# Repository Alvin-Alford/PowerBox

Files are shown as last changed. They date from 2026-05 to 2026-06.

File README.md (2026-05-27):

#  PowerBox

> An all-in-one power solution for cyberdecks and portable embedded systems.

PowerBox is my custom-designed PCB that handles USB-C Power Delivery input, dual-cell lithium battery management, balance charging, and regulated power output, all in a single compact board. Designed to push up to **36W** of power to whatever you throw at it.

---

## Overview
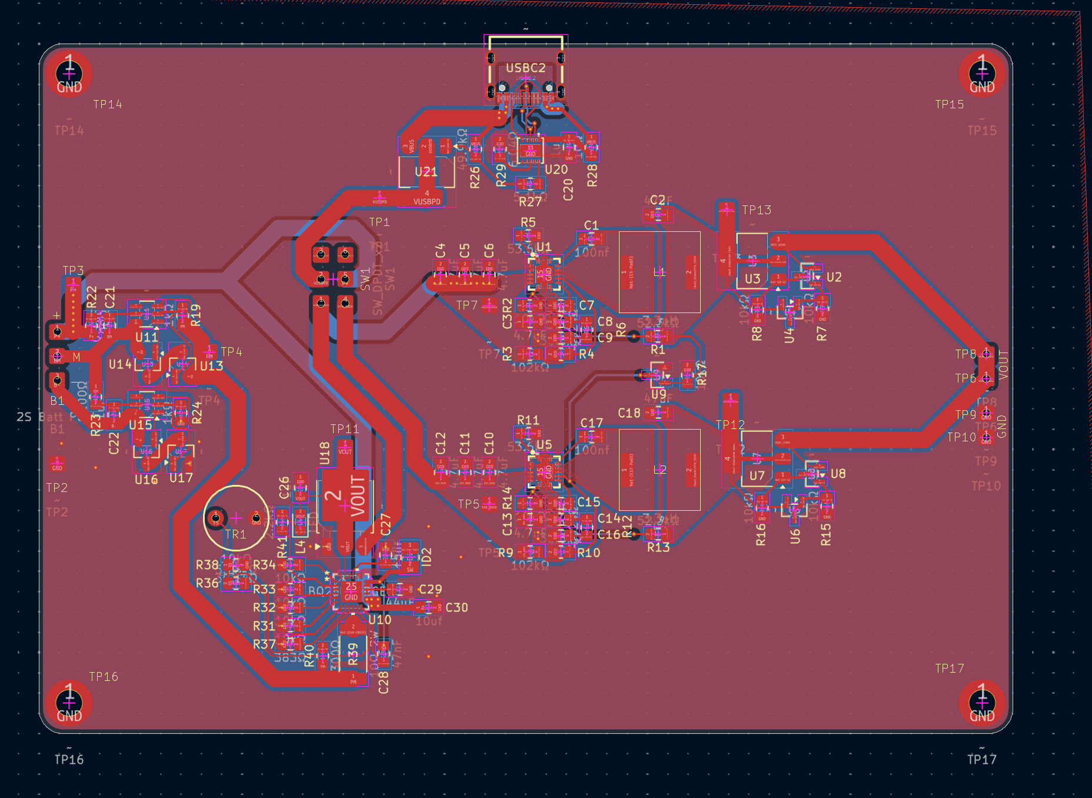
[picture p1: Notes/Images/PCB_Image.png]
PCB_IMAGE


*PowerBox was built to power DIY cyberdecks and portable computing projects that need more juice than a standard battery banks can provide.*

---

## Components

PowerBox is built around **7 core subsystems**:

### 1. USB-C Power Delivery Input
A USB-C port paired with a **PD sink controller** that negotiates **12V** from a PD-capable charger. At full load the circuit can draw up to **36W** which is well beyond what standard 5V USB can supply.

### 2. Dual Buck DC-DC Converters (×2)
Two **TPS54620** synchronous step-down converters provide regulated output voltages. The TPS54620 is a 6A, 17V capable device giving plenty of headroom for demanding loads.

### 3. Ideal Diode Circuits (×2)
When USB-C power is present, the battery-fed bucks are switched off to prevent backfeeding the charger. This creates a condition where the buck converter inputs can see negative voltages which is outside their rated range. The ideal diode circuits clamp this safely, acting as electronic diodes with near-zero forward voltage drop.

### 4. BMS Circuit (DW01A)
A battery management system built around the **DW01A** which is a popular and proven lithium-ion protection IC. Handles over-charge, over-discharge, and short-circuit protection for the cell pack.

### 5. 2S Balance Charger (BQ2588RGER)
A proper **2-series balance charger** using TI's **BQ2588RGER**, capable of up to **2A** charge current. Keeps both cells at equal state-of-charge for longevity and safety.

---

##  PCB

The PCB design files are in the [`PowerBox_PCB/`](./PowerBox_PCB) directory. Output gerbers and fabrication files are in [`Output/`](./Output).

---

## Design Logic

```
USB-C PD (12V, 36W)
        │
        ├──► Buck 1 (TPS54620) ──► Ideal Diode ──► Output Rail A
        │
        ├──► Buck 2 (TPS54620) ──► Ideal Diode ──► Output Rail B
        │
        └──► BQ2588RGER Balance Charger ──► 2S Li-Ion Pack
                                                  │
                                              DW01A BMS
                                                  │
                                            Battery Output
```

**Why did I choose 36W / USB-C PD?**

A 2S lithium pack needs to charge while simultaneously powering the system. At full system load, 15W standard USB-C isn't enough, it can't even charge an open MacBook. Requesting **12V via PD** and pulling up to **3A** gives the 36W headroom needed to charge the battery *and* run the load at the same time.

**Why two cells?**

More cells = more capacity. More capacity = the circuit can sustain high loads without the cells entering stress territory. A single-cell design at 36W draw would be asking for trouble (and possibly a fire).

---

## Repository Structure

```
PowerBox/
├── Notes/           # Design notes and calculations
├── Output/          # Gerber files and fabrication outputs
├── Parts/           # Bill of materials and component info
└── PowerBox_PCB/    # KiCad / PCB design files
```

---

## Key ICs

| Component | Part Number | Function |
|---|---|---|
| Buck Converter | TPS54620 | 6A, 17V synchronous step-down |
| Balance Charger | BQ2588RGER | 2S Li-Ion balance charger, 2A |
| BMS Controller | DW01A | Li-Ion protection IC |
| PD Sink | *(see Parts/)* | USB-C PD 12V negotiation |

---

## Zine

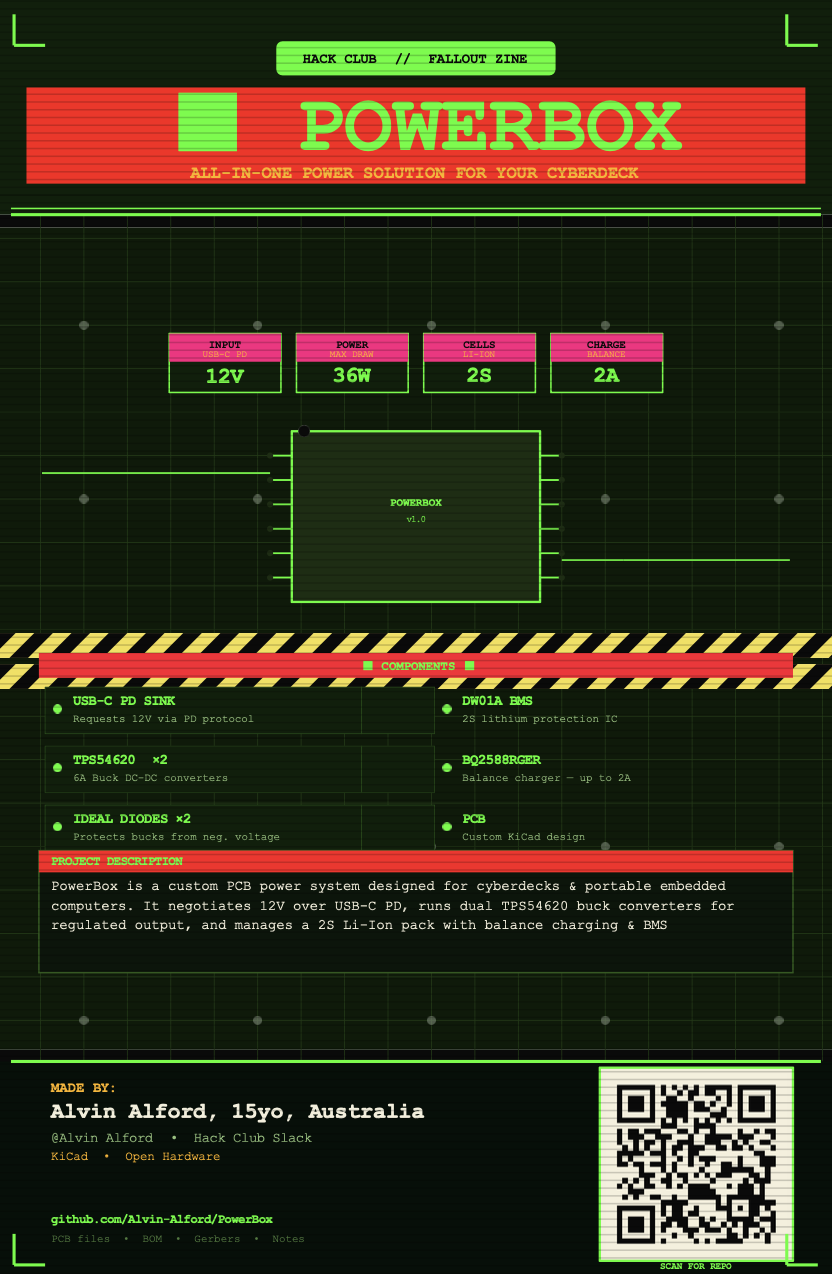
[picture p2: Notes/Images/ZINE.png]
ZINE


---

## License

See [LICENSE](./LICENSE) for details.

---

*Built by [Alvin-Alford](https://github.com/Alvin-Alford)*

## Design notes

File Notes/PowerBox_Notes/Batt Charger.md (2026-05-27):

1. Power Supply: https://www.lcsc.com/product-detail/C2847000.html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
2. https://www.lcsc.com/product-detail/C2761614.html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
3. https://www.lcsc.com/product-detail/C3013385.html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
4. https://www.lcsc.com/product-detail/C435392.html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
5.

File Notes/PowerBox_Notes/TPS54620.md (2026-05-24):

1. [TPS54620RHLR | TI | Price | In Stock | LCSC Electronics](https://www.lcsc.com/product-detail/C263274.html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)  
2. [NR1050M3R3N | Coilank | Price | In Stock | LCSC Electronics](https://www.lcsc.com/product-detail/C47327102.html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)  
3. [AT0805BRD074K02L | YAGEO | Price | In Stock | LCSC Electronics](https://www.lcsc.com/product-detail/C856950.html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)  
4. [FRC0805F1023TS | FOJAN | Price | In Stock | LCSC Electronics](https://www.lcsc.com/product-detail/C2999517.html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)  
5. [FRC0805F3652TS | FOJAN | Price | In Stock | LCSC Electronics](https://www.lcsc.com/product-detail/C2999585.html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)  
6. [ARG05BTC5232 | Viking | Price | In Stock | LCSC Electronics](https://www.lcsc.com/product-detail/C2758300.html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)  
7. [FRC0805F5362TS | FOJAN | Price | In Stock | LCSC Electronics](https://www.lcsc.com/product-detail/C5153984.html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)  
8. [FRC0805F1002TS | FOJAN | Price | In Stock | LCSC Electronics](https://www.lcsc.com/product-detail/C2907219.html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)  
9. [CL21A475KAQNNNE | Samsung Electro-Mechanics | Price | In Stock | LCSC Electronics](https://www.lcsc.com/product-detail/C1779.html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)  
10. [CL21C222JBFNNNE | Samsung Electro-Mechanics | Price | In Stock | LCSC Electronics](https://www.lcsc.com/product-detail/C28260.html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)  
11. [CL21A476MQYNNNE | Samsung Electro-Mechanics | Price | In Stock | LCSC Electronics](https://www.lcsc.com/product-detail/C16780.html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)  
12. [CC0805KRX7R9BB104 | YAGEO | Price | In Stock | LCSC Electronics](https://www.lcsc.com/product-detail/C49678.html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)  
13. [CC0805KRX7R9BB183 | YAGEO | Price | In Stock | LCSC Electronics](https://www.lcsc.com/product-detail/C113857.html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)  
14. [CC0805JRNPO9BN300 | YAGEO | Price | In Stock | LCSC Electronics](https://www.lcsc.com/product-detail/C107114.html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)  
15. [TPS54620 data sheet, product information and support | TI.com](https://www.ti.com/product/TPS54620)  
16. [TPS54620EVM-374 Evaluation board | TI.com](https://www.ti.com/tool/TPS54620EVM-374#tech-docs)  
17. [TPS54620 Step-Down Converter Evaluation Module User's Guide (Rev. B) - slvu281b.pdf](https://www.ti.com/lit/ug/slvu281b/slvu281b.pdf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)  
18. [Datasheet - LCSC Electronics](https://www.lcsc.com/datasheet/C263274.pdf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)  
19. [Power Designer](https://webench.ti.com/power-designer/switching-regulator/customize/1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)  
20. [Ceramic Capacitors | Electronic Components Distributor | LCSC Electronics](https://www.lcsc.com/category/1142.html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)

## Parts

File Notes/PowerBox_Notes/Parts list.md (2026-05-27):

1. [[TPS54620]]
2. [[Ideal Diode]]
3. [[Switch over controller]]
4. [[Batt Charger]]
5. [[BMS]]
6. [[USBPD]]

https://www.lcsc.com/product-detail/C84256.html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

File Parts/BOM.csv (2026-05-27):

Index | LCSC# | MPN | Manufacturer | Package | Customer # | Description | RoHS | Quantity | MOQ | Multiple | Unit Price($) | Extended Price($) | Product Link
1 | C84256 | NCD0805R1 | NATIONSTAR | 0805 |  | Red 630nm LED Indication - Discrete 1.6V~2.6V 0805 | yes | 50 | 50 | 50 | 0.0134 | 0.67 | https://www.lcsc.com/product-detail/C84256.html
2 | C2847000 | LM1084RS-5.0 | HTC | TO-252-3L |  | 5V Positive Fixed TO-252-3L Voltage Regulators - Linear, Low Drop Out (LDO) Regulators RoHS | yes | 3 | 1 | 1 | 0.5310 | 1.59 | https://www.lcsc.com/product-detail/C2847000.html
3 | C2761614 | BQ25887RGER | TI | QFN-24-EP(4x4) |  | Battery Balancing IC Lithium-ion/Polymer QFN-24-EP(4x4) | yes | 3 | 1 | 1 | 2.9554 | 8.87 | https://www.lcsc.com/product-detail/C2761614.html
4 | C3013385 | FRP2512J100 TS | FOJAN | 2512 |  | 2W 10Ω 200V Thick Film Resistor ±200ppm/℃ ±5% 2512 Chip Resistor - Surface Mount RoHS | yes | 20 | 20 | 20 | 0.0344 | 0.69 | https://www.lcsc.com/product-detail/C3013385.html
5 | C435392 | DFE252012F-1R0M=P2 | muRata | 1008 |  | 3.3A 1uH ±20% 4.7A 40mΩ 1008 Fixed Inductors RoHS | yes | 5 | 5 | 5 | 0.1374 | 0.69 | https://www.lcsc.com/product-detail/C435392.html
6 | C351410 | DW01A | PUOLOP | SOT-23-6L |  | Lithium Battery SOT-23-6L Battery Management RoHS | yes | 20 | 20 | 20 | 0.0428 | 0.86 | https://www.lcsc.com/product-detail/C351410.html
7 | C20917 | AO3400A | AOS | SOT-23 |  | N-Channel 30V Surface Mount SOT-23-3L | yes | 10 | 5 | 5 | 0.0828 | 0.83 | https://www.lcsc.com/product-detail/C20917.html
8 | C154901 | DMP6023LE-13 | DIODES | SOT-223 |  | P-Channel 60V 7A 2W Surface Mount SOT-223 | yes | 5 | 1 | 1 | 0.5912 | 2.96 | https://www.lcsc.com/product-detail/C154901.html
9 | C53444 | MMBT3906LT1G | onsemi | SOT-23 |  | Bipolar (BJT) Transistor PNP 40V 200mA 250MHz 225mW Surface Mount SOT-23 | yes | 50 | 50 | 50 | 0.0175 | 0.88 | https://www.lcsc.com/product-detail/C53444.html
10 | C263274 | TPS54620RHLR | TI | VQFN-14-EP(3.5x3.5) |  | 1.6MHz Step-down type Adjustable 800mV~15V 6A 4.5V~17V VQFN-14-EP(3.5x3.5) Voltage Regulators - DC DC Switching Regulators RoHS | yes | 4 | 1 | 1 | 0.9462 | 3.78 | https://www.lcsc.com/product-detail/C263274.html
11 | C47327102 | NR1050M3R3N | Coilank | SMD,10x10mm |  | 7.5A 3.3uH ±20% 14mΩ 10.7A SMD,10x10mm Fixed Inductors RoHS | yes | 5 | 5 | 5 | 0.1074 | 0.54 | https://www.lcsc.com/product-detail/C47327102.html
12 | C856950 | AT0805BRD074K02L | YAGEO | 0805 |  | 125mW 4.02kΩ Thin Film Resistor ±25ppm/℃ ±0.1% 0805 Chip Resistor - Surface Mount RoHS | yes | 10 | 5 | 5 | 0.0950 | 0.95 | https://www.lcsc.com/product-detail/C856950.html
13 | C2999517 | FRC0805F1023TS | FOJAN | 0805 |  | 102kΩ ±1% 125mW 0805 Thick Film Resistor | yes | 100 | 100 | 100 | 0.0018 | 0.18 | https://www.lcsc.com/product-detail/C2999517.html
14 | C2999585 | FRC0805F3652TS | FOJAN | 0805 |  | 36.5kΩ ±1% 125mW 0805 Thick Film Resistor | yes | 100 | 100 | 100 | 0.0013 | 0.13 | https://www.lcsc.com/product-detail/C2999585.html
15 | C2758300 | ARG05BTC5232 | Viking | 0805 |  | 52.3kΩ ±0.1% 125mW 0805 Thin Film Resistor | yes | 20 | 20 | 20 | 0.0341 | 0.68 | https://www.lcsc.com/product-detail/C2758300.html
16 | C5153984 | FRC0805F5362TS | FOJAN | 0805 |  | 53.6kΩ ±1% 125mW 0805 Thick Film Resistor | yes | 100 | 100 | 100 | 0.0019 | 0.19 | https://www.lcsc.com/product-detail/C5153984.html
17 | C2907219 | FRC0805F1002TS | FOJAN | 0805 |  | 10kΩ ±1% 125mW 0805 Thick Film Resistor | yes | 100 | 100 | 100 | 0.0021 | 0.21 | https://www.lcsc.com/product-detail/C2907219.html
18 | C1779 | CL21A475KAQNNNE | Samsung Electro-Mechanics | 0805 |  | 4.7uF ±10% 25V Ceramic Capacitor X5R 0805 | yes | 20 | 20 | 20 | 0.0184 | 0.37 | https://www.lcsc.com/product-detail/C1779.html
19 | C28260 | CL21C222JBFNNNE | Samsung Electro-Mechanics | 0805 |  | 2.2nF ±5% 50V Ceramic Capacitor C0G 0805 | yes | 10 | 10 | 10 | 0.0295 | 0.30 | https://www.lcsc.com/product-detail/C28260.html
20 | C16780 | CL21A476MQYNNNE | Samsung Electro-Mechanics | 0805 |  | 47uF ±20% 6.3V Ceramic Capacitor X5R 0805 | yes | 10 | 10 | 10 | 0.0556 | 0.56 | https://www.lcsc.com/product-detail/C16780.html
21 | C49678 | CC0805KRX7R9BB104 | YAGEO | 0805 |  | 100nF ±10% 50V Ceramic Capacitor X7R 0805 | yes | 100 | 100 | 100 | 0.0058 | 0.58 | https://www.lcsc.com/product-detail/C49678.html
22 | C113857 | CC0805KRX7R9BB183 | YAGEO | 0805 |  | 18nF ±10% 50V Ceramic Capacitor X7R 0805 | yes | 100 | 100 | 100 | 0.0082 | 0.82 | https://www.lcsc.com/product-detail/C113857.html
23 | C107114 | CC0805JRNPO9BN300 | YAGEO | 0805 |  | 30pF ±5% 50V Ceramic Capacitor NP0 0805 | yes | 100 | 100 | 100 | 0.0076 | 0.76 | https://www.lcsc.com/product-detail/C107114.html
24 | C7471904 | HUSB238_002DD | Hynetek | DFN-10L(3x3) |  | DFN-10L(3x3) Interface Controllers RoHS | yes | 3 | 1 | 1 | 0.5107 | 1.53 | https://www.lcsc.com/product-detail/C7471904.html
25 | C165948 | TYPE-C-31-M-12 | Korean Hroparts Elec | SMD |  | USB-C (USB TYPE-C) Receptacle Connector 16 Position Surface Mount | yes | 5 | 5 | 5 | 0.1719 | 0.86 | https://www.lcsc.com/product-detail/C165948.html
26 | C440198 | GRM21BR61H106KE43L | muRata | 0805 |  | 10uF ±10% 50V Ceramic Capacitor X5R 0805 | yes | 20 | 10 | 10 | 0.0795 | 1.59 | https://www.lcsc.com/product-detail/C440198.html
27 | C107154 | CC0805KRX7R9BB473 | YAGEO | 0805 |  | 47nF ±10% 50V Ceramic Capacitor X7R 0805 | yes | 200 | 100 | 100 | 0.0074 | 1.48 | https://www.lcsc.com/product-detail/C107154.html
28 | C5439718 | MF52B103F3435L100 | SURGING | - |  | NTC Thermistor 10kΩ | yes | 5 | 5 | 5 | 0.1121 | 0.56 | https://www.lcsc.com/product-detail/C5439718.html
29 | C2907232 | FRC0805F1001TS | FOJAN | 0805 |  | 1kΩ ±1% 125mW 0805 Thick Film Resistor | yes | 100 | 100 | 100 | 0.0020 | 0.20 | https://www.lcsc.com/product-detail/C2907232.html
30 | C17415 | 0805W8F100JT5E | UNI-ROYAL | 0805 |  | 10Ω ±1% 125mW 0805 Thick Film Resistor | yes | 100 | 100 | 100 | 0.0029 | 0.29 | https://www.lcsc.com/product-detail/C17415.html
31 | C105577 | RC0805FR-07100RL | YAGEO | 0805 |  | 125mW 100Ω 150V Thick Film Resistor ±100ppm/℃ ±1% 0805 Chip Resistor - Surface Mount RoHS | yes | 100 | 100 | 100 | 0.0027 | 0.27 | https://www.lcsc.com/product-detail/C105577.html
32 | C2930203 | FRC0805F4992TS | FOJAN | 0805 |  | 49.9kΩ ±1% 125mW 0805 Thick Film Resistor | yes | 100 | 100 | 100 | 0.0021 | 0.21 | https://www.lcsc.com/product-detail/C2930203.html
33 | C27834 | 0805W8F5101T5E | UNI-ROYAL | 0805 |  | 5.1kΩ ±1% 125mW 0805 Thick Film Resistor | yes | 100 | 100 | 100 | 0.0027 | 0.27 | https://www.lcsc.com/product-detail/C27834.html
34 | C2933464 | FRC0805F5231TS | FOJAN | 0805 |  | 5.23kΩ ±1% 125mW 0805 Thick Film Resistor | yes | 100 | 100 | 100 | 0.0020 | 0.20 | https://www.lcsc.com/product-detail/C2933464.html
35 | C2999498 | FRC0805F3830TS | FOJAN | 0805 |  | 383Ω ±1% 125mW 0805 Thick Film Resistor | yes | 100 | 100 | 100 | 0.0019 | 0.19 | https://www.lcsc.com/product-detail/C2999498.html
36 | C2933410 | FRC0805F3012TS | FOJAN | 0805 |  | 30.1kΩ ±1% 125mW 0805 Thick Film Resistor | yes | 100 | 100 | 100 | 0.0020 | 0.20 | https://www.lcsc.com/product-detail/C2933410.html
37 | C2907254 | FRC0805F3000TS | FOJAN | 0805 |  | 300Ω ±1% 125mW 0805 Thick Film Resistor | yes | 100 | 100 | 100 | 0.0021 | 0.21 | https://www.lcsc.com/product-detail/C2907254.html
38 | C17520 | 0805W8F2201T5E | UNI-ROYAL | 0805 |  | 2.2kΩ ±1% 125mW 0805 Thick Film Resistor | yes | 100 | 100 | 100 | 0.0022 | 0.22 | https://www.lcsc.com/product-detail/C17520.html

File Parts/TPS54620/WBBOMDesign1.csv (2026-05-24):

Part | Manufacturer | Part Number | Quantity | Price ($) | Footprint (mm²) | Description
Rcomp | Vishay-Dale | CRCW04024K02FKED | 1 | 0.01 | 3 | Resistance: 4.02 kΩ Tolerance: 1.0% Power: 63 mW
U1 | Texas Instruments | TPS54620RHLR | 1 | 2.374 | 21.62
Rent | Vishay-Dale | CRCW0402102KFKED | 1 | 0.01 | 3 | Resistance: 102 kΩ Tolerance: 1.0% Power: 63 mW
Renb | Yageo | RC0201FR-0736K5L | 1 | 0.01 | 2.08 | Resistance: 36.5 kΩ Tolerance: 1.0% Power: 50 mW
Cin | MuRata | GRM31CR71H475KA12L | 3 | 0.1 | 10.92 | Cap: 4.7 µF Total Derated Cap: 10 µF VDC: 50 V ESR: 3 mΩ Package: 1206
Css | Samsung Electro-Mechanics | CL21C222JBFNNNE | 1 | 0.02 | 6.75 | Cap: 2.2 nF Total Derated Cap: 2.2 nF VDC: 50 V ESR: 0 Ω Package: 0805
Rfbb | Yageo | RC0201FR-0710KL | 1 | 0.01 | 2.08 | Resistance: 10 kΩ Tolerance: 1.0% Power: 50 mW
Cout | MuRata | GRM32ER61C476KE15L | 1 | 0.17 | 14.7 | Cap: 47 µF Total Derated Cap: 32 µF VDC: 16 V ESR: 3.04 mΩ Package: 1210
Rfbt | Vishay-Dale | CRCW040252K3FKED | 1 | 0.01 | 3 | Resistance: 52.3 kΩ Tolerance: 1.0% Power: 63 mW
Cboot | AVX | 08053C104KAT2A | 1 | 0.01 | 6.75 | Cap: 100 nF Total Derated Cap: 100 nF VDC: 25 V ESR: 280 mΩ Package: 0805
L1 | NIC Components | NPI52P3R3MTRF | 1 | 0.5482 | 444.63 | L: 3.3 µH DCR: 14 mΩ IDC: 10 A
Ccomp | Kemet | C1812C183J5GACTU | 1 | 0.71 | 23.1 | Cap: 18 nF Total Derated Cap: 18 nF VDC: 50 V ESR: 0 Ω Package: 1812
Rt | Vishay-Dale | CRCW040253K6FKED | 1 | 0.01 | 3 | Resistance: 53.6 kΩ Tolerance: 1.0% Power: 63 mW
Cinx | Taiyo Yuden | MSAST21GAB5475MTNA01 | 1 | 0.03223 | 6.75 | Cap: 4.7 µF Total Derated Cap: 4.7 µF VDC: 25 V ESR: 8.21 mΩ Package: 0805
Ccomp2 | Kemet | C0402C300J5GACTU | 1 | 0.01 | 3 | Cap: 30 pF Total Derated Cap: 30 pF VDC: 50 V ESR: 0 Ω Package: 0402

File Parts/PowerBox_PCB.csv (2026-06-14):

Id | Designator | Footprint | Quantity | Designation | Supplier and ref
1 | B1 | 2S Batt Pack | 1 | 2S Batt Pack
2 | C1, C17 | C_0805_2012Metric_Pad1.18x1.45mm_HandSolder | 2 | 100nf
3 | C2, C19, C23 | C_1210_3225Metric_Pad1.33x2.70mm_HandSolder | 3 | 47uF
4 | C3, C4, C5, C6, C10, C11, C12, C13, C18 | C_0805_2012Metric_Pad1.18x1.45mm_HandSolder | 9 | 4.7uF
5 | C7, C15 | C_0805_2012Metric_Pad1.18x1.45mm_HandSolder | 2 | 2.2uF
6 | C8, C14 | C_0805_2012Metric_Pad1.18x1.45mm_HandSolder | 2 | 30pF
7 | C9, C16 | C_0805_2012Metric_Pad1.18x1.45mm_HandSolder | 2 | 18uF
8 | C20 | C_0805_2012Metric_Pad1.18x1.45mm_HandSolder | 1 | 1uF
9 | C21, C22 | C_0805_2012Metric_Pad1.18x1.45mm_HandSolder | 2 | 0.1uF
10 | C27, C30 | C_0805_2012Metric_Pad1.18x1.45mm_HandSolder | 2 | 10uf
11 | C28 | C_0805_2012Metric_Pad1.18x1.45mm_HandSolder | 1 | 47nF
12 | ID2 | L_1008_2520Metric_Pad1.43x2.20mm_HandSolder | 1 | 1uh
13 | L1, L2 | IND-SMD_L8.5-W8.0_PSPMAA0803H-330M-ANP | 2 | 3.3uH
14 | L3, L4, L5, L6 | LED_0805_2012Metric_Pad1.15x1.40mm_HandSolder | 4 | LED
15 | R1, R13 | R_0805_2012Metric_Pad1.20x1.40mm_HandSolder | 2 | 52.3kΩ
16 | R2, R7, R8, R14, R15, R16, R17, R29, R31, R32, R33, R34 | R_0805_2012Metric_Pad1.20x1.40mm_HandSolder | 12 | 10kΩ
17 | R3, R9 | R_0805_2012Metric_Pad1.20x1.40mm_HandSolder | 2 | 102kΩ
18 | R4, R10 | R_0805_2012Metric_Pad1.20x1.40mm_HandSolder | 2 | 36.5kΩ
19 | R5, R11 | R_0805_2012Metric_Pad1.20x1.40mm_HandSolder | 2 | 53.6kΩ
20 | R6, R12 | R_0805_2012Metric_Pad1.20x1.40mm_HandSolder | 2 | 4.02kΩ
21 | R18, R19, R20, R21, R24, R25 | R_0805_2012Metric_Pad1.20x1.40mm_HandSolder | 6 | 1kΩ
22 | R22, R23 | R_0805_2012Metric_Pad1.20x1.40mm_HandSolder | 2 | 100Ω
23 | R28, R30 | R_0805_2012Metric_Pad1.20x1.40mm_HandSolder | 2 | 100kΩ
24 | R36 | C_0805_2012Metric_Pad1.18x1.45mm_HandSolder | 1 | 5.23kΩ
25 | R37 | C_0805_2012Metric_Pad1.18x1.45mm_HandSolder | 1 | 383Ω
26 | R38 | C_0805_2012Metric_Pad1.18x1.45mm_HandSolder | 1 | 30.1kΩ
27 | R39 | R_2512_6332Metric_Pad1.40x3.35mm_HandSolder | 1 | 10Ω_2W
28 | R40 | R_0805_2012Metric_Pad1.20x1.40mm_HandSolder | 1 | 300Ω
29 | R41 | R_0805_2012Metric_Pad1.20x1.40mm_HandSolder | 1 | 2.2kΩ
30 | SW1 | SwitchPads | 1 | SW_DPDT_x2
31 | TP1, TP2, TP3, TP4, TP5, TP7, TP9, TP10, TP11, TP12, TP13 | PAD-2x2 | 11 | ~
32 | TP14, TP15, TP16, TP17 | M3-Pad | 4 | ~
33 | TP18, TP19 | PAD-2x2-ThroughHole | 2 | ~
34 | TR1 | ThermistorPads | 1 | 10kΩ
35 | U1, U5 | VQFN-14_L3.5-W3.5-P0.50-TL-EP_TPS54622RHLT | 2 | TPS54620
36 | U2, U4, U6, U8, U12 | SOT-23 | 5 | MMBT3906LT1G
37 | U3, U7, U21 | SOT-223 | 3 | DMP6023LE-13
38 | U9 | SOT-23 | 1 | 2N7002
39 | U10 | VQFN24_RGE_TEX | 1 | BQ25887RGER
40 | U11, U15 | SOT-23-6_Handsoldering | 2 | DW01A
41 | U13, U14, U16, U17 | SOT-23_Handsoldering | 4 | AO3400A
42 | U18 | TO-252-3_TabPin2 | 1 | LM1084RS-5.0
43 | U19, U22 | SOT-23 | 2 | BC817
44 | U23 | SOT-23-6 | 1 | CH221K
45 | USBC2 | USB-C_SMD-TYPE-C-31-M-12_1 | 1 | USBC_Port

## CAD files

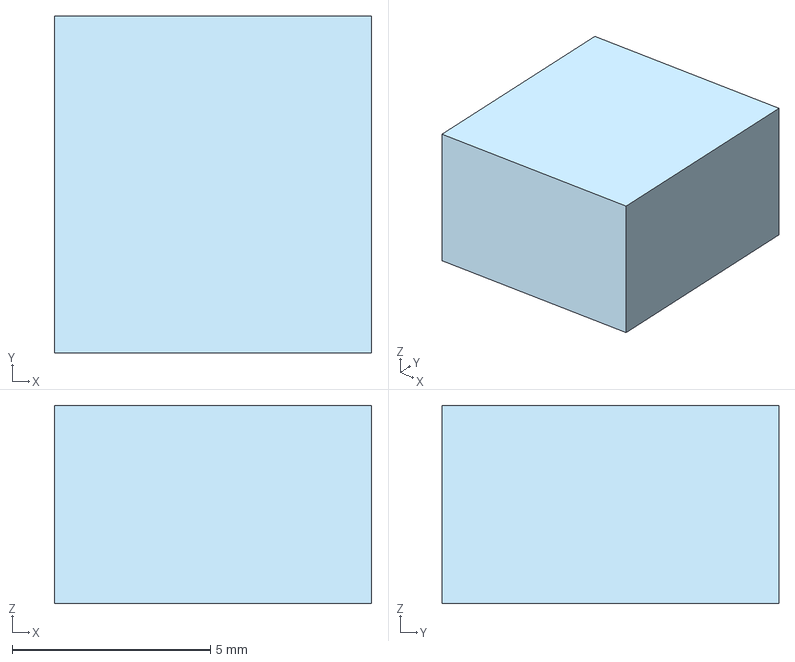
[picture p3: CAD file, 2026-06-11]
Parts/Inductor - Part 1(1).step
8.00 x 8.50 x 5.00 mm

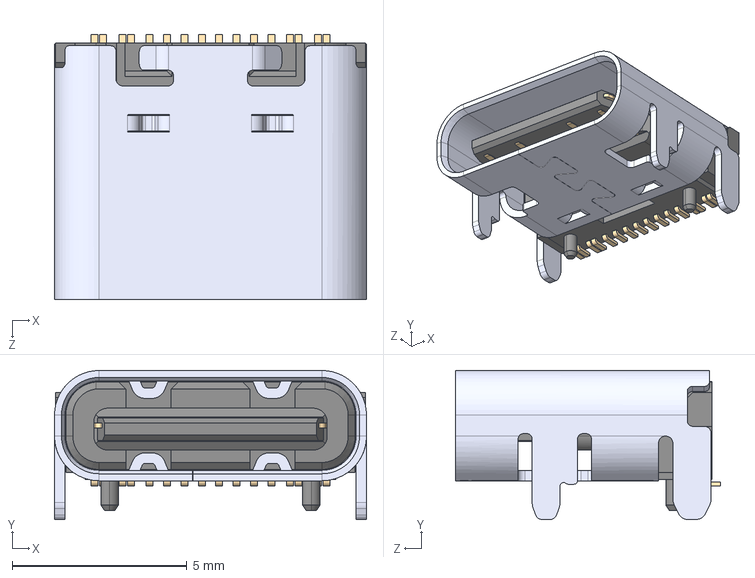
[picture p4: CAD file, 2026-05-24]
Parts/USBC/UJ20-C-H-G-SMT-1-P16-TR/UJ20-C-H-G-SMT-1-P16-TR.step
8.94 x 4.27 x 7.60 mm

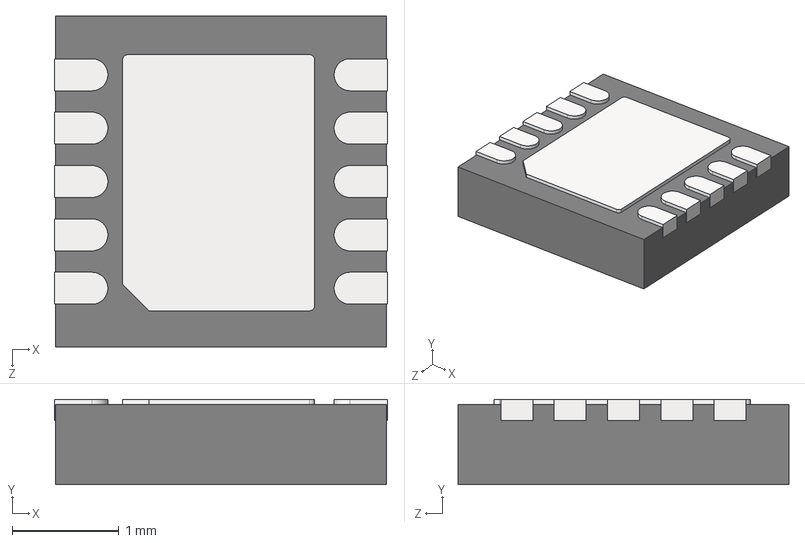
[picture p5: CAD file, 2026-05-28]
PowerBox_PCB/3D_files/DFN-10-3x3-0_5.STEP
3.12 x 0.8 x 3.10 mm
TP

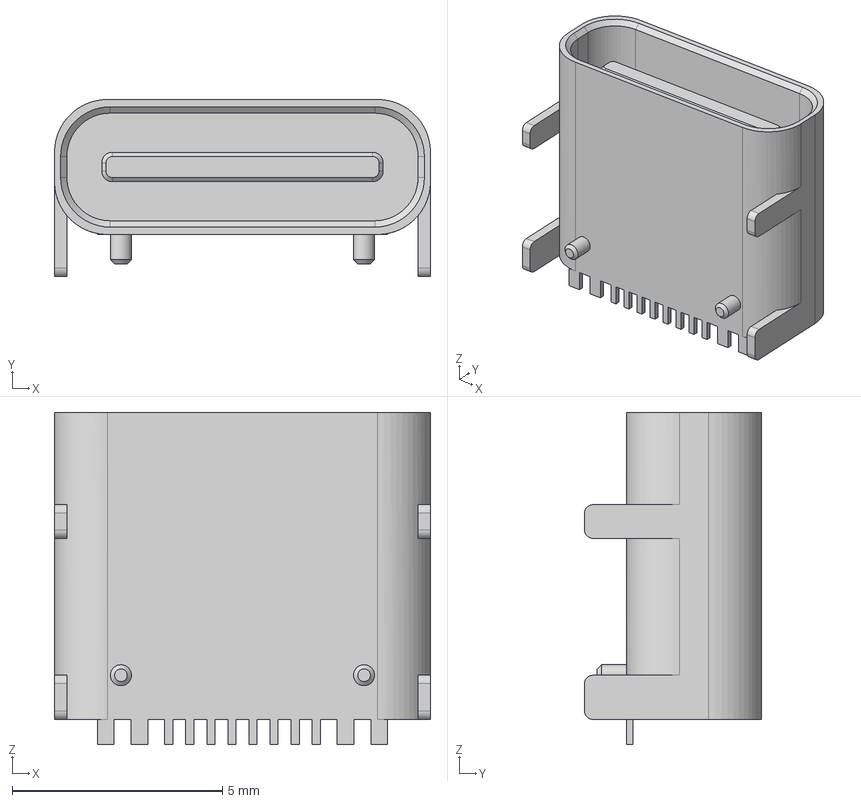
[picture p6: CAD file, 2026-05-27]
PowerBox_PCB/3D_files/HRO TYPE-C-31-M-12.step
8.94 x 4.21 x 7.90 mm

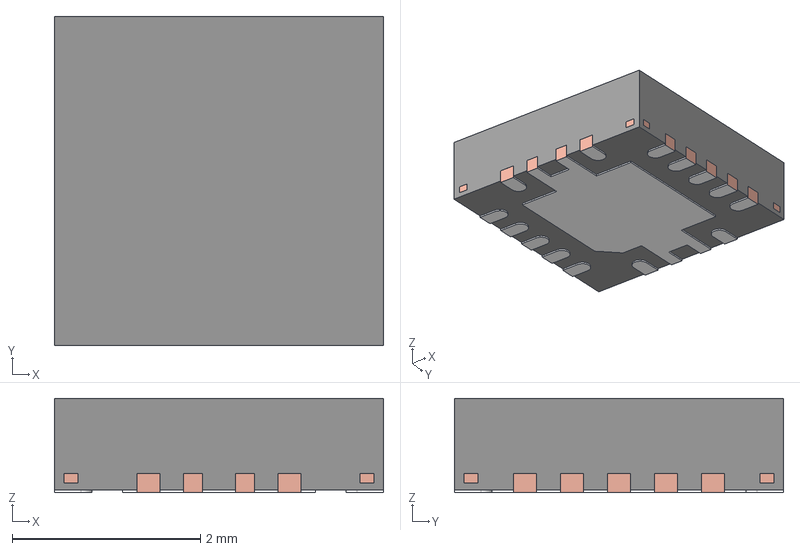
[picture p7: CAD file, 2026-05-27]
PowerBox_PCB/3D_files/RHL0014A.stp
3.50 x 3.50 x 1.00 mm
FRAME

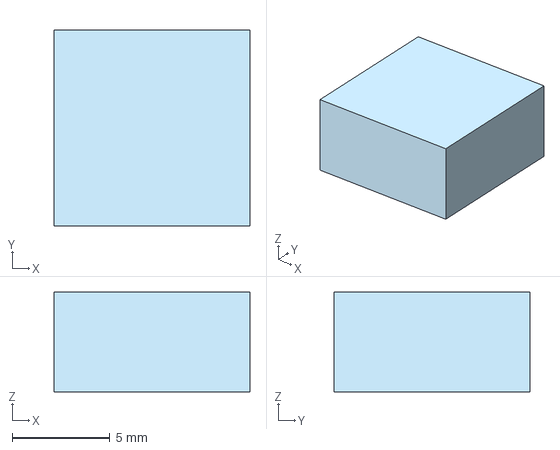
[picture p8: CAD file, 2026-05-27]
PowerBox_PCB/3D_files/Inductor - Part 1.step
10.0 x 10.0 x 5.10 mm

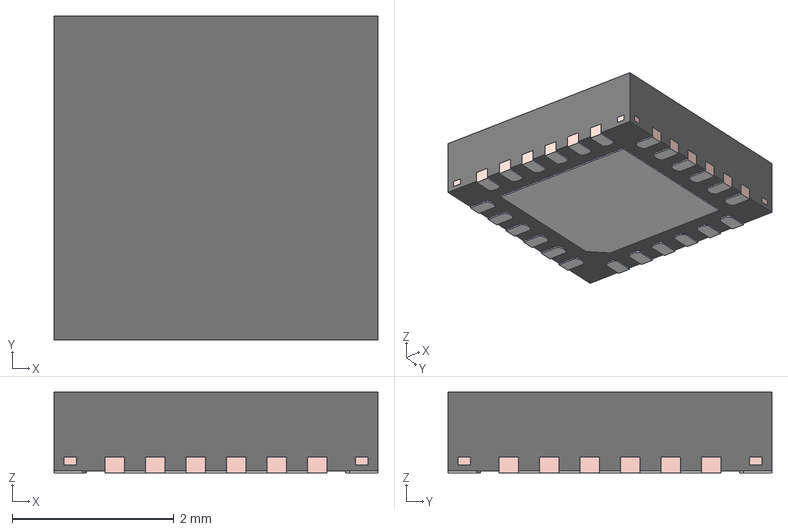
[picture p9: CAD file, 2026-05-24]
PowerBox_PCB/3D_files/RGE0024H.stp
4.00 x 4.00 x 1.00 mm
FRAME

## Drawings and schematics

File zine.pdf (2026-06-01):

# POWERBOX POWERBOX

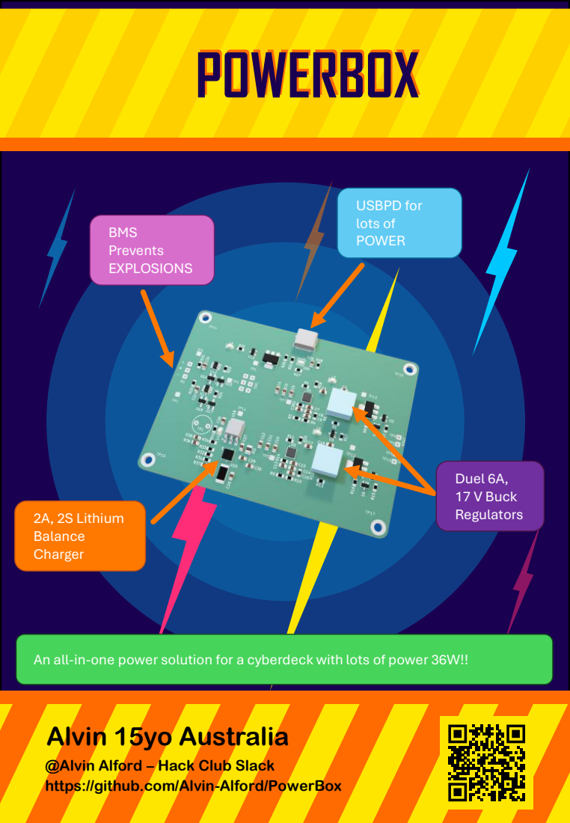
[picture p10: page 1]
Alvin 15yo Australia; Duel 6A, 17 V Buck Regulators 2A, 2S Lithium Balance Charger; BMS Prevents EXPLOSIONS; USBPD for lots of POWER

An all-in-one power solution for a cyberdeck with lots of power 36W!!

@Alvin Alford – Hack Club Slack
https://github.com/Alvin-Alford/PowerBox

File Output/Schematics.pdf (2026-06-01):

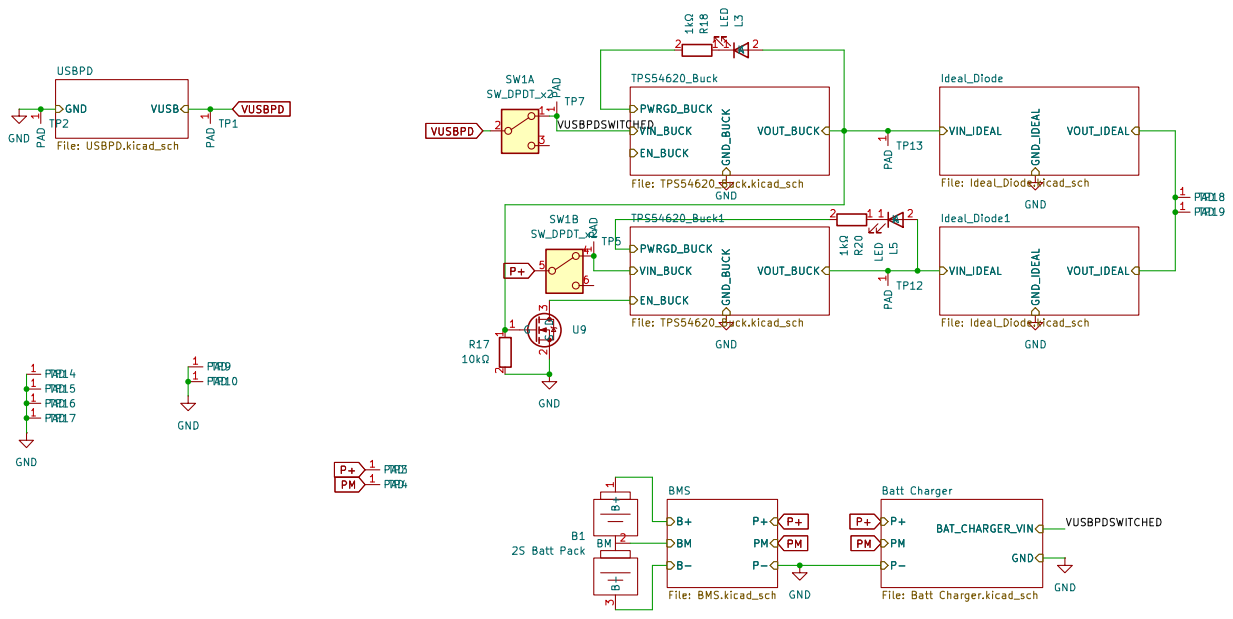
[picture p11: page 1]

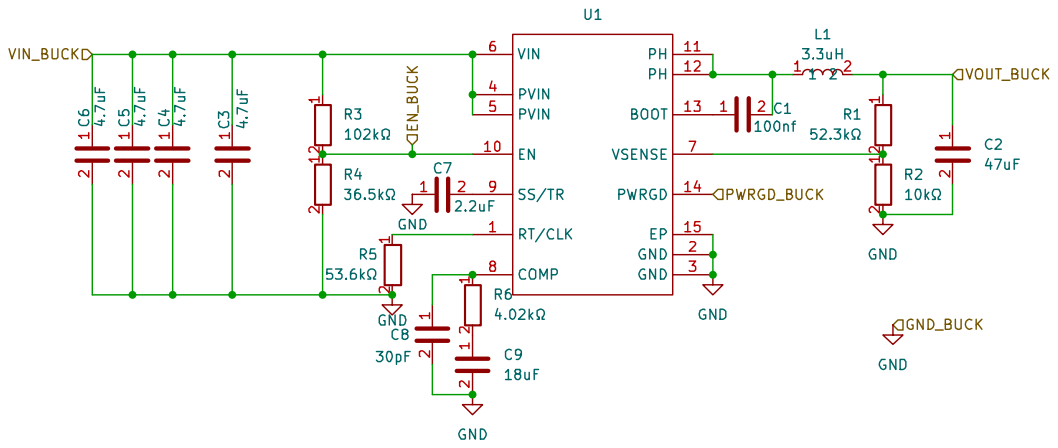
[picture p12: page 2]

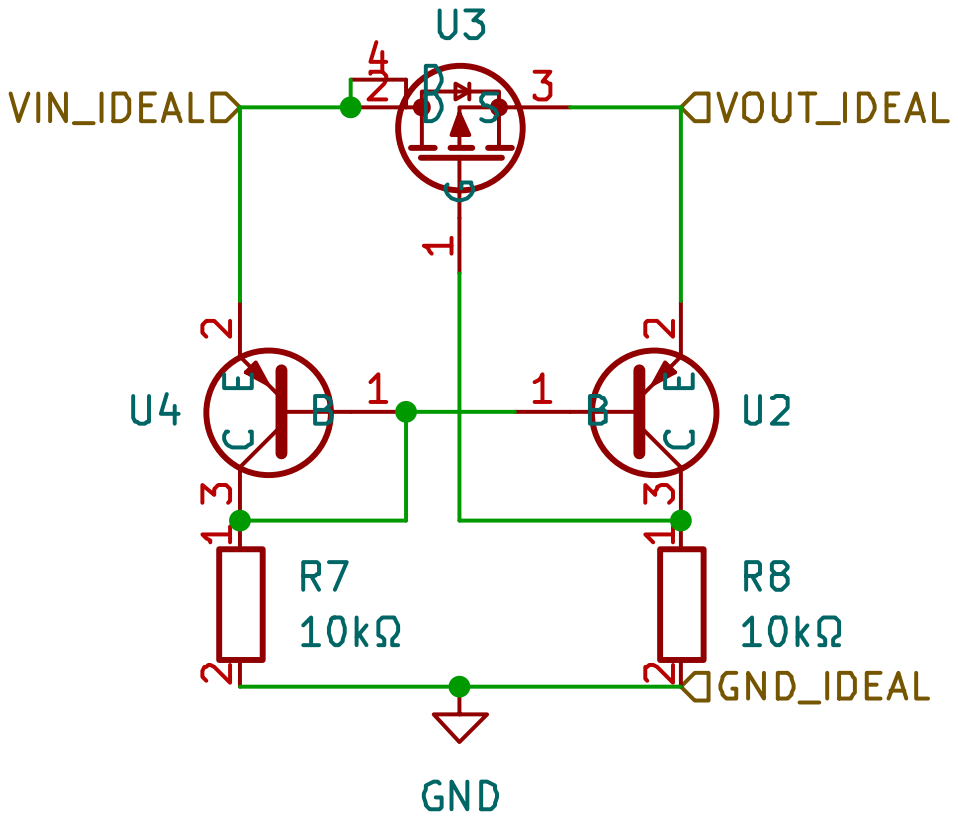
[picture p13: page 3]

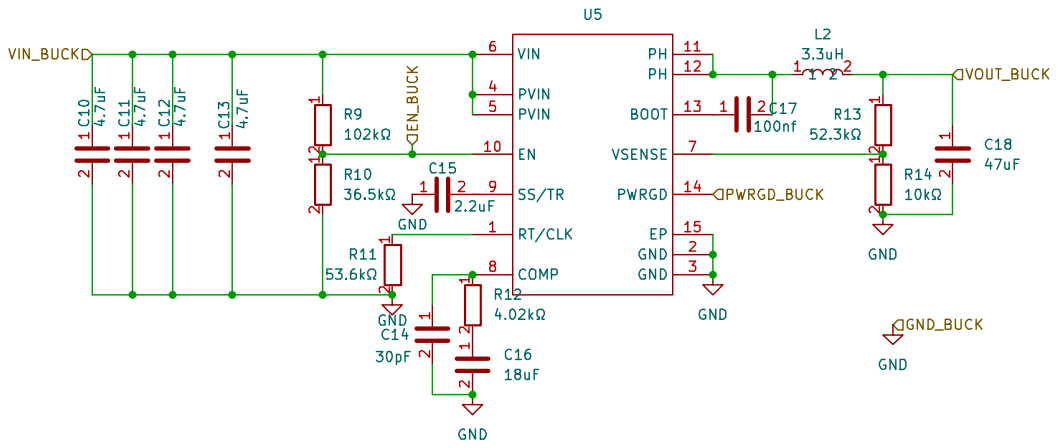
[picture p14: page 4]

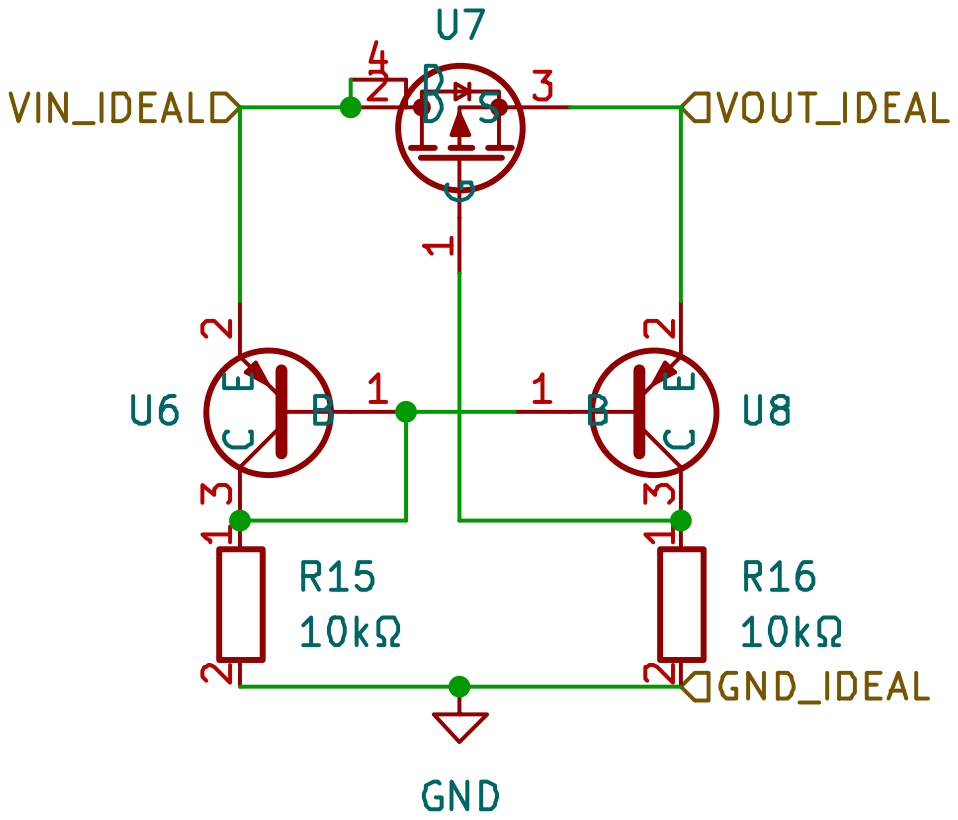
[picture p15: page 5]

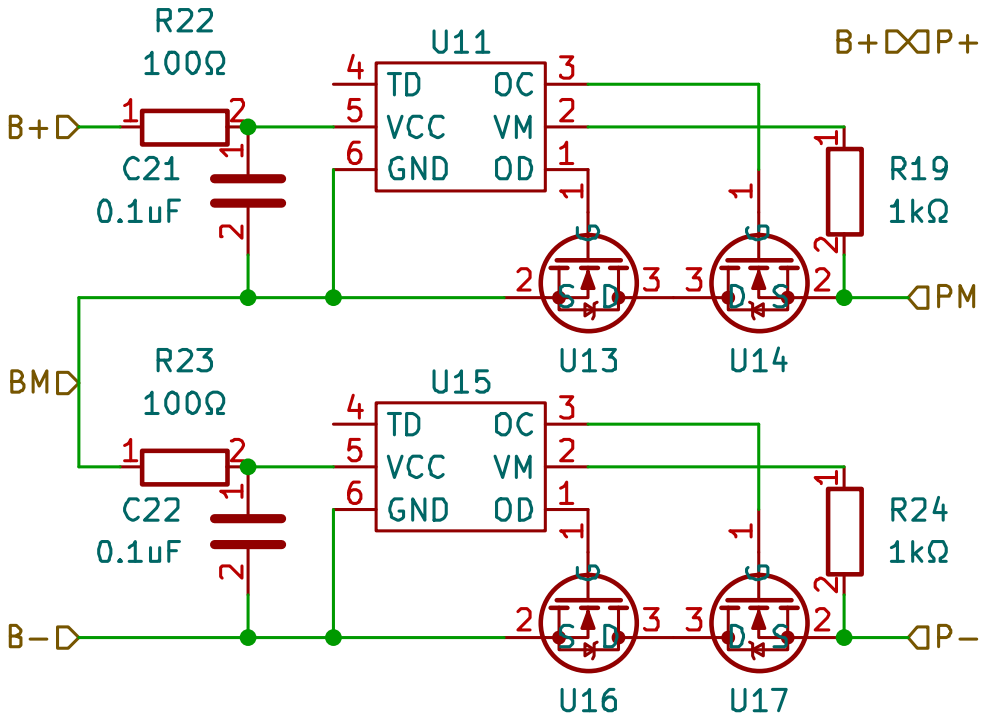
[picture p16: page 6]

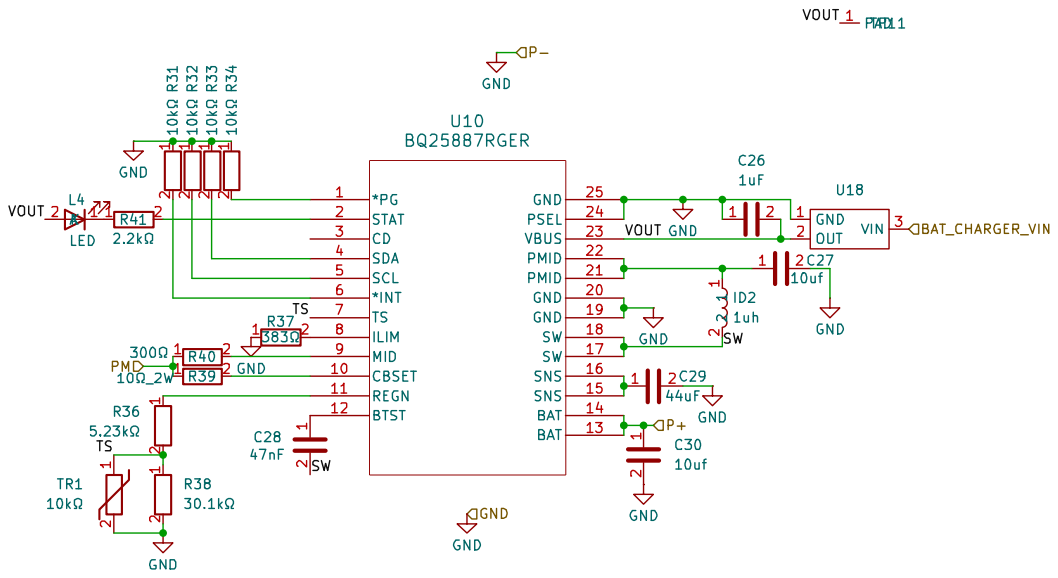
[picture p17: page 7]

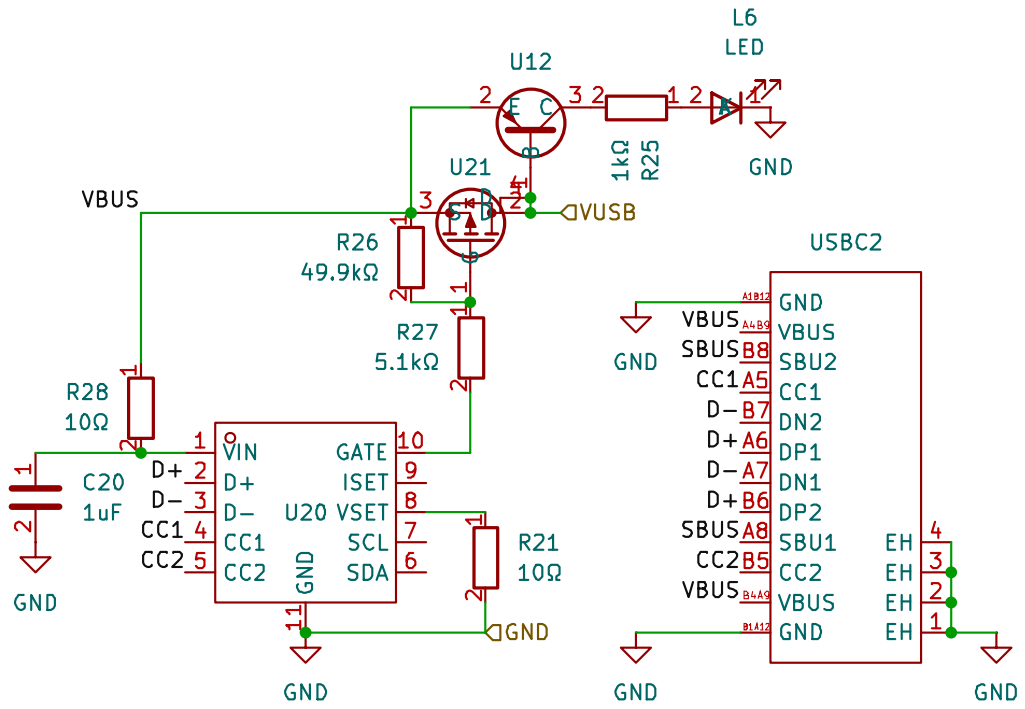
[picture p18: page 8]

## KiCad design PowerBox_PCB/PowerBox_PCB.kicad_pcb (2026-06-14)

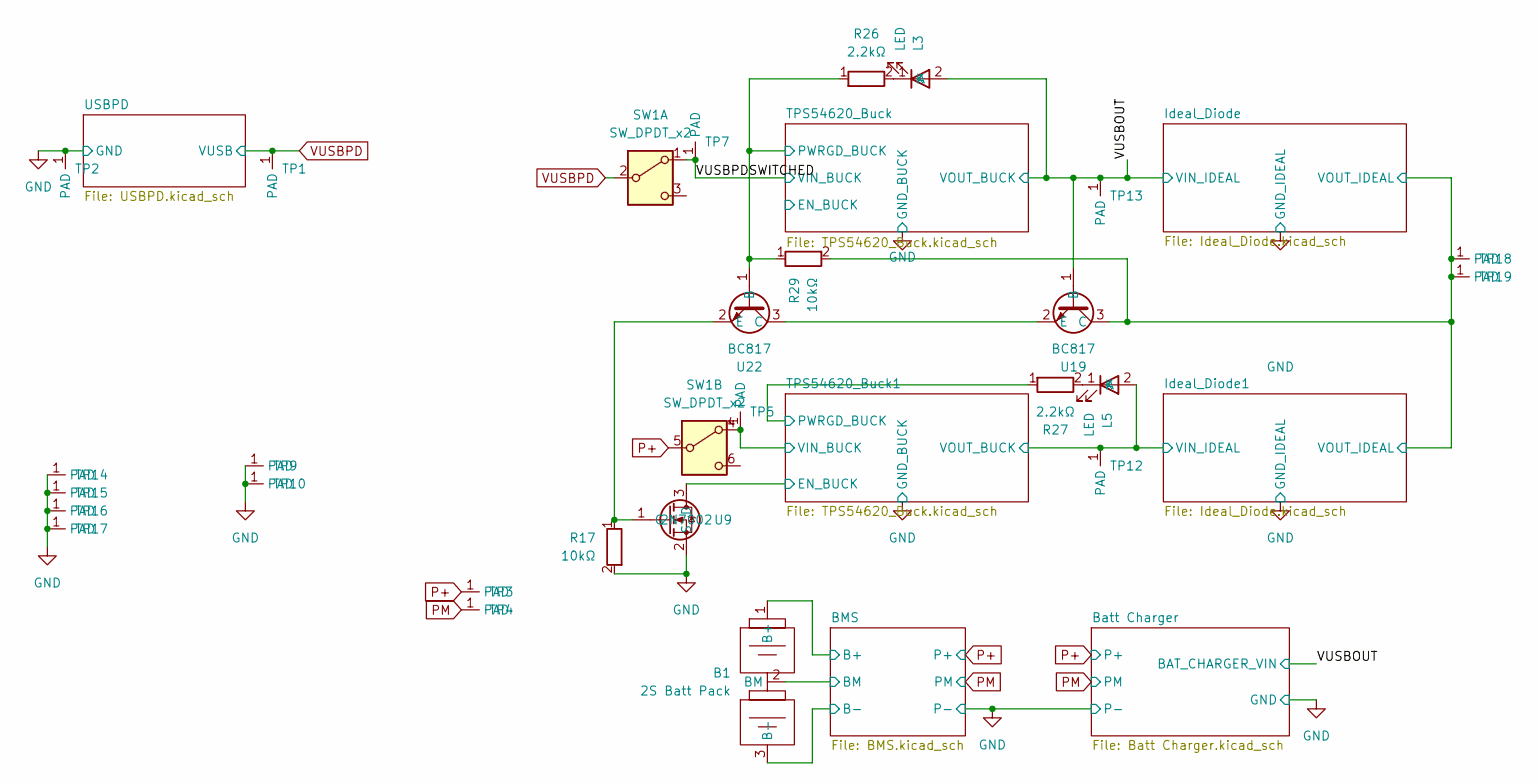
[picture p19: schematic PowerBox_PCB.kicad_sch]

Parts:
B1: 2S Batt Pack
L3, L5: LED; LED_0805_2012Metric_Pad1.15x1.40mm_HandSolder
R17, R29: 10kΩ; R_0805_2012Metric_Pad1.20x1.40mm_HandSolder
R26, R27: 2.2kΩ; R_0805_2012Metric_Pad1.20x1.40mm_HandSolder
SW1: SW_DPDT_x2; SwitchPads
TP1, TP2, TP3, TP4, TP5, TP7, TP9, TP10, TP12, TP13: PAD-2x2
TP14, TP15, TP16, TP17: M3-Pad
TP18, TP19: PAD-2x2-ThroughHole
U9: 2N7002; SOT-23
U19, U22: BC817; SOT-23

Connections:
/BMS/B-: B1.3 (B-); also elsewhere on the board
/BMS/BM: B1.2 (BM); also elsewhere on the board
/Ideal_Diode1/VIN_IDEAL: L5.2 (A), TP12.1 (PAD_1); also elsewhere on the board
/Ideal_Diode/VOUT_IDEAL: R29.2, TP18.1 (PAD_1), TP19.1 (PAD_1), U19.3 (C); also elsewhere on the board
/TPS54620_Buck1/EN_BUCK: U9.3 (D); also elsewhere on the board
/TPS54620_Buck1/PWRGD_BUCK: R27.1; also elsewhere on the board
/TPS54620_Buck1/VIN_BUCK: SW1.4 (A), TP5.1 (PAD_1); also elsewhere on the board
/TPS54620_Buck/PWRGD_BUCK: R26.1, R29.1, U22.1 (B); also elsewhere on the board
/VUSBOUT: L3.2 (A), TP13.1 (PAD_1), U19.1 (B); also elsewhere on the board
/VUSBPDSWITCHED: SW1.1 (A), TP7.1 (PAD_1); also elsewhere on the board
GND: R17.2, TP2.1 (PAD_1), TP9.1 (PAD_1), TP10.1 (PAD_1), TP14.1 (PAD_1), TP15.1 (PAD_1), TP16.1 (PAD_1), TP17.1 (PAD_1), U9.2 (S); also elsewhere on the board
unnamed: L3.1 (K), R26.2
unnamed: L5.1 (K), R27.2
unnamed: U19.2 (E), U22.3 (C)
unnamed: R17.1, U9.1 (G), U22.2 (E)
P+: B1.1 (B+), SW1.5 (B), TP3.1 (PAD_1); also elsewhere on the board
PM: TP4.1 (PAD_1); also elsewhere on the board
VUSBPD: SW1.2 (B), TP1.1 (PAD_1); also elsewhere on the board

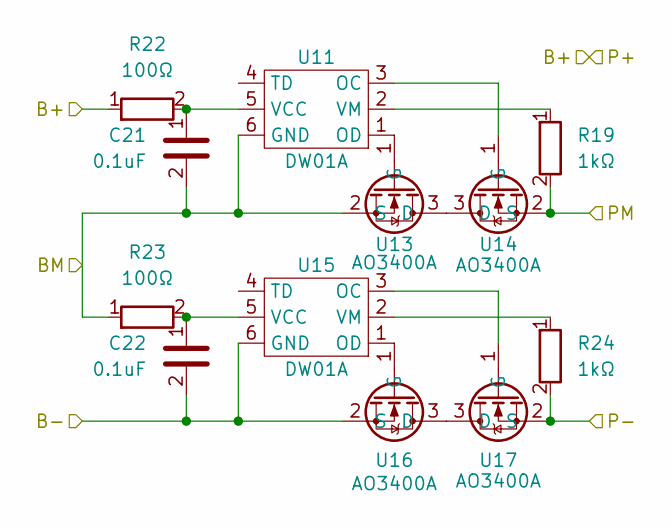
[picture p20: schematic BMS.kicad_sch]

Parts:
C21, C22: 0.1uF; C_0805_2012Metric_Pad1.18x1.45mm_HandSolder
R19, R24: 1kΩ; R_0805_2012Metric_Pad1.20x1.40mm_HandSolder
R22, R23: 100Ω; R_0805_2012Metric_Pad1.20x1.40mm_HandSolder
U11, U15: DW01A; SOT-23-6_Handsoldering
U13, U14, U16, U17: AO3400A; SOT-23_Handsoldering

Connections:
/BMS/B-: C22.2, U15.6 (GND), U16.2 (S); also elsewhere on the board
/BMS/BM: C21.2, R23.1, U11.6 (GND), U13.2 (S); also elsewhere on the board
GND: R24.2, U17.2 (S); also elsewhere on the board
unnamed: U11.3 (OC), U14.1 (G)
unnamed: U11.1 (OD), U13.1 (G)
unnamed: C21.1, R22.2, U11.5 (VCC)
unnamed: R19.1, U11.2 (VM)
unnamed: U13.3 (D), U14.3 (D)
unnamed: U15.3 (OC), U17.1 (G)
unnamed: U15.1 (OD), U16.1 (G)
unnamed: C22.1, R23.2, U15.5 (VCC)
unnamed: R24.1, U15.2 (VM)
unnamed: U16.3 (D), U17.3 (D)
P+: R22.1; also elsewhere on the board
PM: R19.2, U14.2 (S); also elsewhere on the board

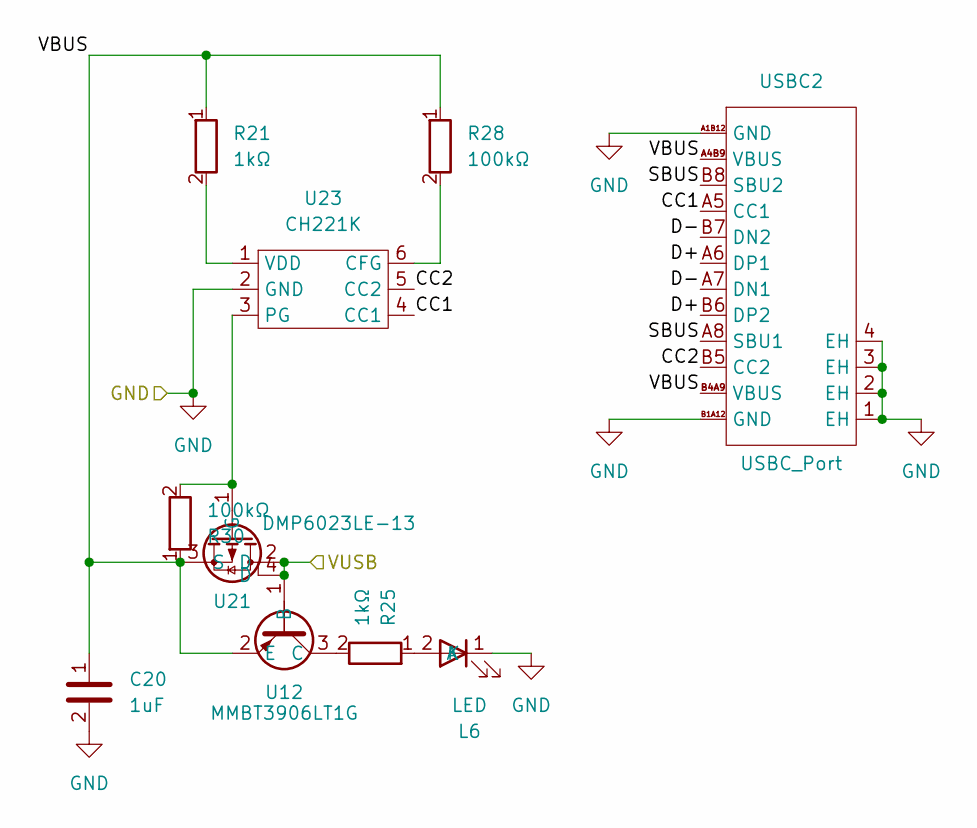
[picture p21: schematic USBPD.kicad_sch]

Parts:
C20: 1uF; C_0805_2012Metric_Pad1.18x1.45mm_HandSolder
L6: LED; LED_0805_2012Metric_Pad1.15x1.40mm_HandSolder
R21, R25: 1kΩ; R_0805_2012Metric_Pad1.20x1.40mm_HandSolder
R28, R30: 100kΩ; R_0805_2012Metric_Pad1.20x1.40mm_HandSolder
U12: MMBT3906LT1G; SOT-23
U21: DMP6023LE-13; SOT-223
U23: CH221K; SOT-23-6
USBC2: USBC_Port; USB-C_SMD-TYPE-C-31-M-12_1; Manufacturer Part TYPE-C-31-M-12; LCSC Part Name Type-C 母 卧贴

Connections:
/USBPD/CC1: U23.4 (CC1), USBC2.A5 (CC1)
/USBPD/CC2: U23.5 (CC2), USBC2.B5 (CC2)
/USBPD/D+: USBC2.A6 (DP1), USBC2.B6 (DP2)
/USBPD/D-: USBC2.A7 (DN1), USBC2.B7 (DN2)
/USBPD/SBUS: USBC2.A8 (SBU1), USBC2.B8 (SBU2)
/USBPD/VBUS: C20.1, R21.1, R28.1, R30.1, U12.2 (E), U21.3 (S), USBC2.A4B9 (VBUS), USBC2.B4A9 (VBUS)
GND: C20.2, L6.1 (K), U23.2 (GND), USBC2.1 (EH), USBC2.2 (EH), USBC2.3 (EH), USBC2.4 (EH), USBC2.A1B12 (GND), USBC2.B1A12 (GND); also elsewhere on the board
unnamed: L6.2 (A), R25.1
unnamed: R25.2, U12.3 (C)
unnamed: R30.2, U21.1 (G), U23.3 (PG)
unnamed: R28.2, U23.6 (CFG)
unnamed: R21.2, U23.1 (VDD)
VUSBPD: U12.1 (B), U21.2 (D), U21.4 (D); also elsewhere on the board

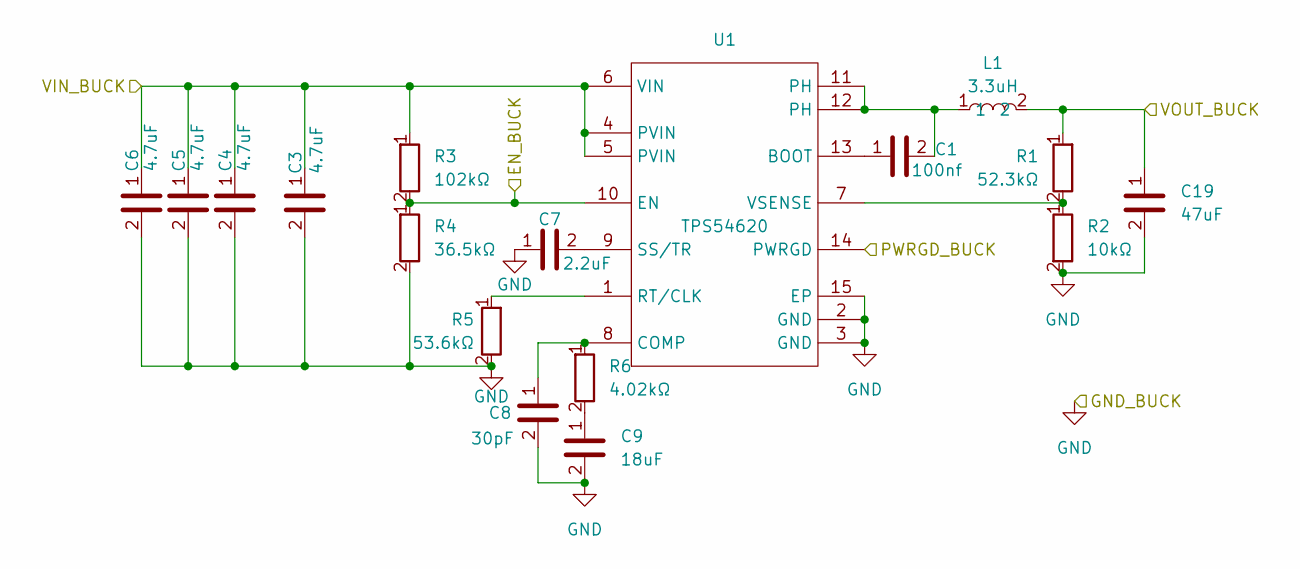
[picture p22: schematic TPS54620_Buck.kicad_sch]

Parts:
C1: 100nf; C_0805_2012Metric_Pad1.18x1.45mm_HandSolder
C3, C4, C5, C6: 4.7uF; C_0805_2012Metric_Pad1.18x1.45mm_HandSolder
C7: 2.2uF; C_0805_2012Metric_Pad1.18x1.45mm_HandSolder
C8: 30pF; C_0805_2012Metric_Pad1.18x1.45mm_HandSolder
C9: 18uF; C_0805_2012Metric_Pad1.18x1.45mm_HandSolder
C19: 47uF; C_1210_3225Metric_Pad1.33x2.70mm_HandSolder
L1: 3.3uH; IND-SMD_L8.5-W8.0_PSPMAA0803H-330M-ANP
R1: 52.3kΩ; R_0805_2012Metric_Pad1.20x1.40mm_HandSolder
R2: 10kΩ; R_0805_2012Metric_Pad1.20x1.40mm_HandSolder
R3: 102kΩ; R_0805_2012Metric_Pad1.20x1.40mm_HandSolder
R4: 36.5kΩ; R_0805_2012Metric_Pad1.20x1.40mm_HandSolder
R5: 53.6kΩ; R_0805_2012Metric_Pad1.20x1.40mm_HandSolder
R6: 4.02kΩ; R_0805_2012Metric_Pad1.20x1.40mm_HandSolder
U1: TPS54620; VQFN-14_L3.5-W3.5-P0.50-TL-EP_TPS54622RHLT; Manufacturer Part TPS54620RHLR; LCSC Part Name 17V输入6A同步降压转换器

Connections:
/TPS54620_Buck/EN_BUCK: R3.2, R4.1, U1.10 (EN)
/TPS54620_Buck/PWRGD_BUCK: U1.14 (PWRGD); also elsewhere on the board
/VUSBOUT: C19.1, L1.2, R1.1; also elsewhere on the board
/VUSBPDSWITCHED: C3.1, C4.1, C5.1, C6.1, R3.1, U1.4 (PVIN), U1.5 (PVIN), U1.6 (VIN); also elsewhere on the board
GND: C3.2, C4.2, C5.2, C6.2, C7.1, C8.2, C9.2, C19.2, R2.2, R4.2, R5.2, U1.2 (GND), U1.3 (GND), U1.15 (EP); also elsewhere on the board
unnamed: C1.2, L1.1, U1.11 (PH), U1.12 (PH)
unnamed: C9.1, R6.2
unnamed: C1.1, U1.13 (BOOT)
unnamed: C8.1, R6.1, U1.8 (COMP)
unnamed: R5.1, U1.1 (RT/CLK)
unnamed: C7.2, U1.9 (SS/TR)
unnamed: R1.2, R2.1, U1.7 (VSENSE)

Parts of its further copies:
C10, C11, C12, C13: 4.7uF; C_0805_2012Metric_Pad1.18x1.45mm_HandSolder
C14: 30pF; C_0805_2012Metric_Pad1.18x1.45mm_HandSolder
C15: 2.2uF; C_0805_2012Metric_Pad1.18x1.45mm_HandSolder
C16: 18uF; C_0805_2012Metric_Pad1.18x1.45mm_HandSolder
C17: 100nf; C_0805_2012Metric_Pad1.18x1.45mm_HandSolder
C23: 47uF; C_1210_3225Metric_Pad1.33x2.70mm_HandSolder
L2: 3.3uH; IND-SMD_L8.5-W8.0_PSPMAA0803H-330M-ANP
R9: 102kΩ; R_0805_2012Metric_Pad1.20x1.40mm_HandSolder
R10: 36.5kΩ; R_0805_2012Metric_Pad1.20x1.40mm_HandSolder
R11: 53.6kΩ; R_0805_2012Metric_Pad1.20x1.40mm_HandSolder
R12: 4.02kΩ; R_0805_2012Metric_Pad1.20x1.40mm_HandSolder
R13: 52.3kΩ; R_0805_2012Metric_Pad1.20x1.40mm_HandSolder
R14: 10kΩ; R_0805_2012Metric_Pad1.20x1.40mm_HandSolder
U5: TPS54620; VQFN-14_L3.5-W3.5-P0.50-TL-EP_TPS54622RHLT; Manufacturer Part TPS54620RHLR; LCSC Part Name 17V输入6A同步降压转换器

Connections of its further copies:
/Ideal_Diode1/VIN_IDEAL: C23.1, L2.2, R13.1; also elsewhere on the board
/TPS54620_Buck1/EN_BUCK: R9.2, R10.1, U5.10 (EN); also elsewhere on the board
/TPS54620_Buck1/PWRGD_BUCK: U5.14 (PWRGD); also elsewhere on the board
/TPS54620_Buck1/VIN_BUCK: C10.1, C11.1, C12.1, C13.1, R9.1, U5.4 (PVIN), U5.5 (PVIN), U5.6 (VIN); also elsewhere on the board
GND: C10.2, C11.2, C12.2, C13.2, C14.2, C15.1, C16.2, C23.2, R10.2, R11.2, R14.2, U5.2 (GND), U5.3 (GND), U5.15 (EP); also elsewhere on the board
unnamed: C16.1, R12.2
unnamed: C17.2, L2.1, U5.11 (PH), U5.12 (PH)
unnamed: C17.1, U5.13 (BOOT)
unnamed: C14.1, R12.1, U5.8 (COMP)
unnamed: R11.1, U5.1 (RT/CLK)
unnamed: C15.2, U5.9 (SS/TR)
unnamed: R13.2, R14.1, U5.7 (VSENSE)

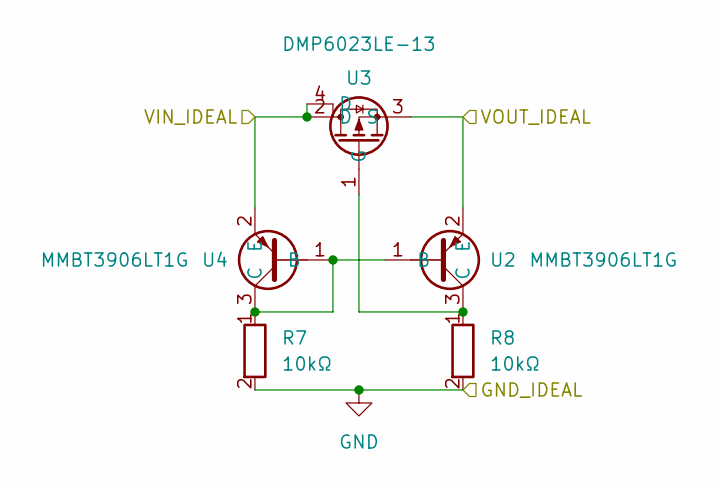
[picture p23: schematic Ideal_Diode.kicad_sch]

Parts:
R7, R8: 10kΩ; R_0805_2012Metric_Pad1.20x1.40mm_HandSolder
U2, U4: MMBT3906LT1G; SOT-23
U3: DMP6023LE-13; SOT-223

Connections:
/Ideal_Diode/VOUT_IDEAL: U2.2 (E), U3.3 (S); also elsewhere on the board
/VUSBOUT: U3.2 (D), U3.4 (D), U4.2 (E); also elsewhere on the board
GND: R7.2, R8.2; also elsewhere on the board
unnamed: R7.1, U2.1 (B), U4.1 (B), U4.3 (C)
unnamed: R8.1, U2.3 (C), U3.1 (G)

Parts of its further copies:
R15, R16: 10kΩ; R_0805_2012Metric_Pad1.20x1.40mm_HandSolder
U6, U8: MMBT3906LT1G; SOT-23
U7: DMP6023LE-13; SOT-223

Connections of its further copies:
/Ideal_Diode1/VIN_IDEAL: U6.2 (E), U7.2 (D), U7.4 (D); also elsewhere on the board
/Ideal_Diode/VOUT_IDEAL: U7.3 (S), U8.2 (E); also elsewhere on the board
GND: R15.2, R16.2; also elsewhere on the board
unnamed: R15.1, U6.1 (B), U6.3 (C), U8.1 (B)
unnamed: R16.1, U7.1 (G), U8.3 (C)

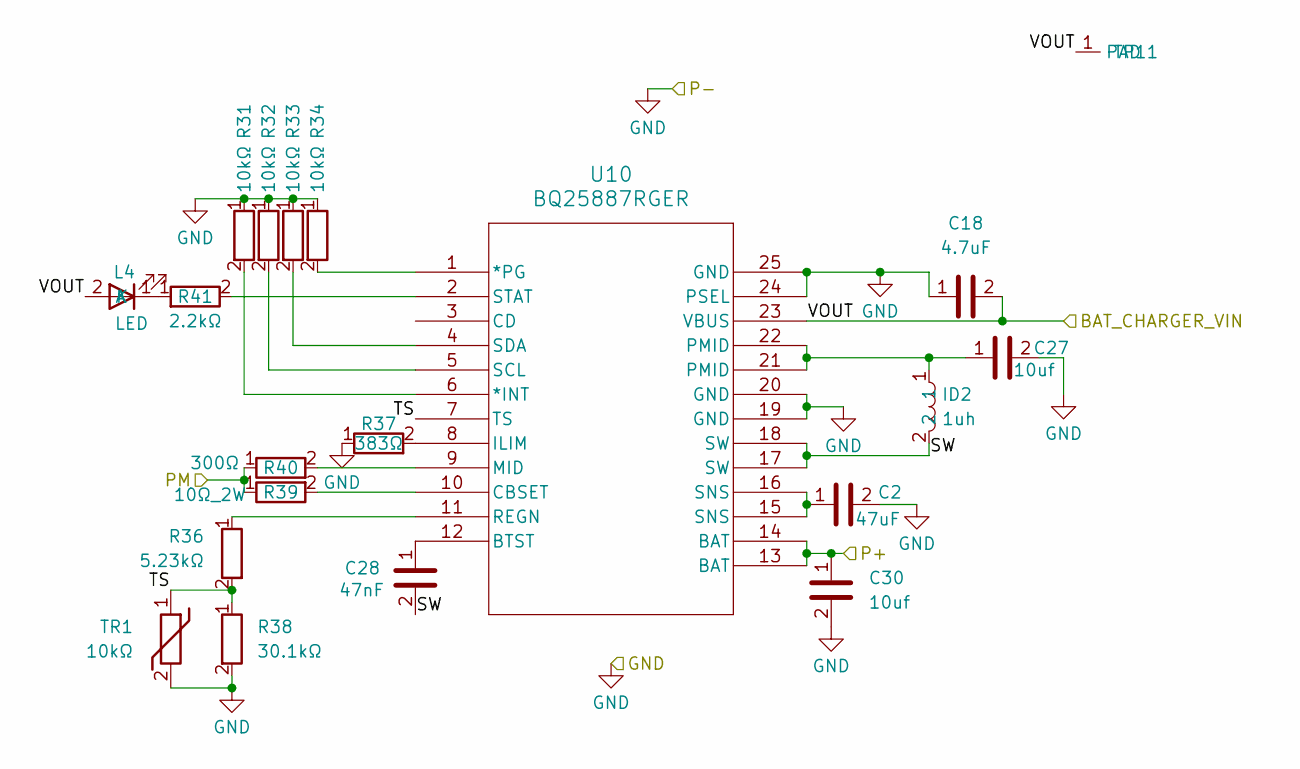
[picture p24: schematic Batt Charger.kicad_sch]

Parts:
C2: 47uF; C_1210_3225Metric_Pad1.33x2.70mm_HandSolder
C18: 4.7uF; C_0805_2012Metric_Pad1.18x1.45mm_HandSolder
C27, C30: 10uf; C_0805_2012Metric_Pad1.18x1.45mm_HandSolder
C28: 47nF; C_0805_2012Metric_Pad1.18x1.45mm_HandSolder
ID2: 1uh; L_1008_2520Metric_Pad1.43x2.20mm_HandSolder
L4: LED; LED_0805_2012Metric_Pad1.15x1.40mm_HandSolder
R31, R32, R33, R34: 10kΩ; R_0805_2012Metric_Pad1.20x1.40mm_HandSolder
R36: 5.23kΩ; C_0805_2012Metric_Pad1.18x1.45mm_HandSolder
R37: 383Ω; C_0805_2012Metric_Pad1.18x1.45mm_HandSolder
R38: 30.1kΩ; C_0805_2012Metric_Pad1.18x1.45mm_HandSolder
R39: 10Ω_2W; R_2512_6332Metric_Pad1.40x3.35mm_HandSolder
R40: 300Ω; R_0805_2012Metric_Pad1.20x1.40mm_HandSolder
R41: 2.2kΩ; R_0805_2012Metric_Pad1.20x1.40mm_HandSolder
TP11: PAD-2x2
TR1: 10kΩ; ThermistorPads
U10: BQ25887RGER; VQFN24_RGE_TEX

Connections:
/Batt Charger/SW: C28.2, ID2.2, U10.17 (SW), U10.18 (SW)
/Batt Charger/TS: R36.2, R38.1, TR1.1, U10.7 (TS)
/VUSBOUT: C18.2, L4.2 (A), TP11.1 (PAD_1), U10.23 (VBUS); also elsewhere on the board
GND: C2.2, C18.1, C27.2, C30.2, R31.1, R32.1, R33.1, R34.1, R37.1, R38.2, TR1.2, U10.19 (GND), U10.20 (GND), U10.24 (PSEL), U10.25 (GND); also elsewhere on the board
unnamed: C2.1, U10.15 (SNS), U10.16 (SNS)
unnamed: C27.1, ID2.1, U10.21 (PMID), U10.22 (PMID)
unnamed: L4.1 (K), R41.1
unnamed: R31.2, U10.6 (*INT)
unnamed: R34.2, U10.1 (*PG)
unnamed: C28.1, U10.12 (BTST)
unnamed: R39.2, U10.10 (CBSET)
unnamed: R37.2, U10.8 (ILIM)
unnamed: R40.2, U10.9 (MID)
unnamed: R36.1, U10.11 (REGN)
unnamed: R32.2, U10.5 (SCL)
unnamed: R33.2, U10.4 (SDA)
unnamed: R41.2, U10.2 (STAT)
P+: C30.1, U10.13 (BAT), U10.14 (BAT); also elsewhere on the board
PM: R39.1, R40.1; also elsewhere on the board

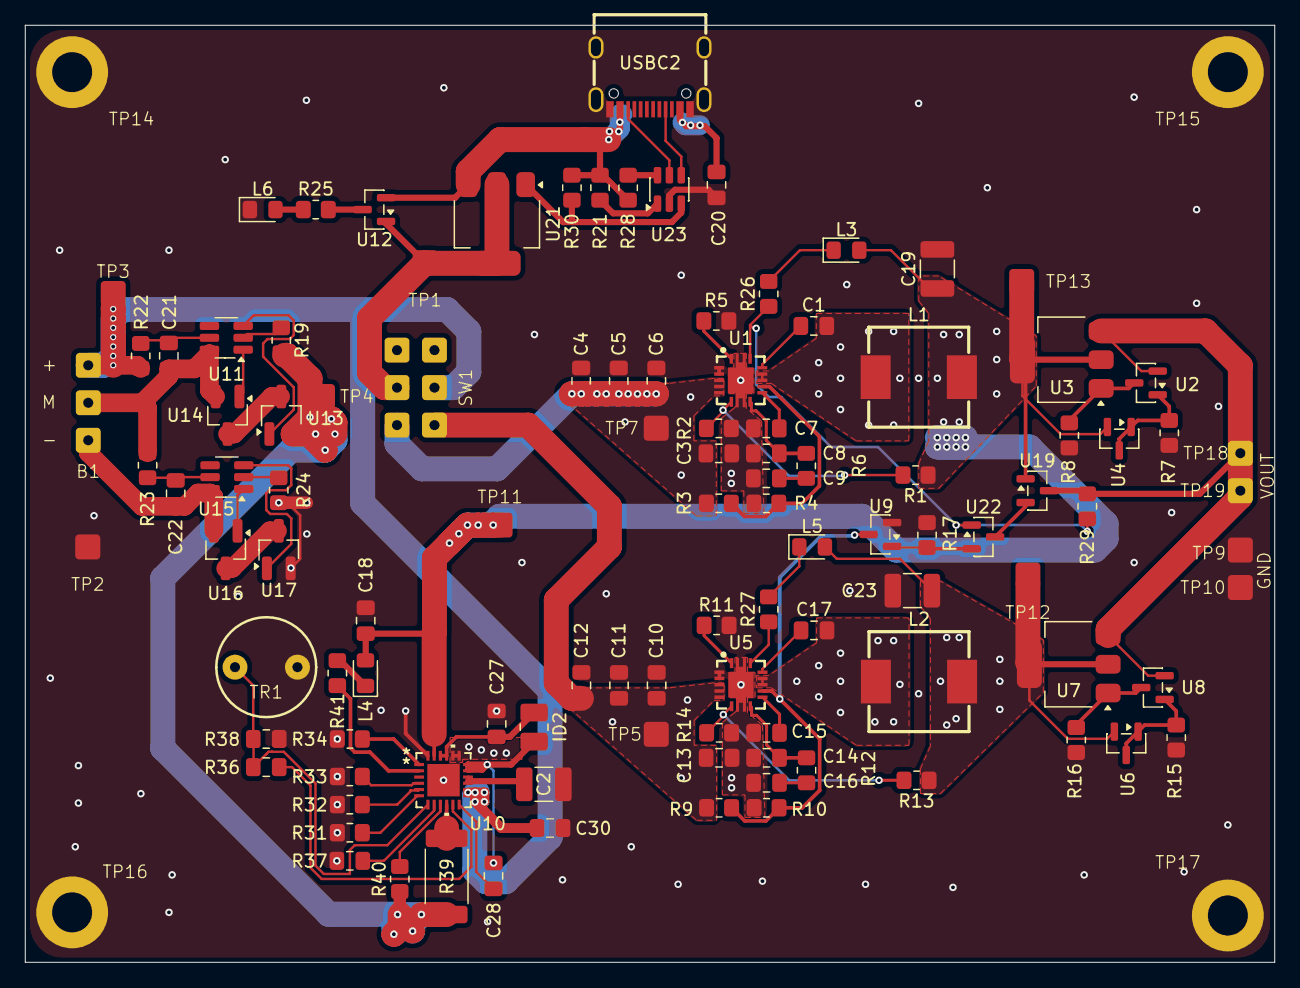
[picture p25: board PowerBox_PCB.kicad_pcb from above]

Board: 2 copper layers, 100.0 x 75.0 mm, 113 parts (0 on the bottom side), 73 nets.

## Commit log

2026-05-21 Added footprints
    Added footprints i made for a earlier project
    [PowerBox_PCB.kicad_pcb, PowerBox_PCB.kicad_sch]
2026-05-24 Added Powersupplys
    Added the TPS54620 as powersupplys and built circuit for it.
    Added A LDO 5v 3A DC-DC VREG for the battery charger
    [CMOS_INVERTER.kicad_sch, Ideal_Diode.kicad_sch, PowerBox_PCB.kicad_pcb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]
2026-05-24 Added USBPD & BMD & BATTCHARGER
    Added USBPD & BMD & BATTCHARGER
    [BMS.kicad_sch, Batt Charger.kicad_sch, PowerBox_PCB.kicad_pcb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]
2026-05-25 Finished
    Basically done
    [Batt Charger.kicad_sch, PowerBox_PCB.kicad_pcb, PowerBox_PCB.kicad_sch]
2026-05-27 e
    e
    [PowerBox_PCB.csv, PowerBox_PCB.kicad_pcb]
2026-05-27 add indicator lights
    add indicator lights
    [PowerBox_PCB.kicad_pcb, PowerBox_PCB.kicad_sch, USBPD.kicad_sch]
2026-05-27 add more stuff for shipping
    [BOM.csv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]
2026-05-27 fixed 3d stuff
    [Inductor - Part 1.step, PowerBox_PCB.kicad_pcb, RHL0014A.stp]
2026-05-27 more model shenaigans
    [HRO TYPE-C-31-M-12.step]
2026-05-28 made board a lot smaller
    board is now 100 x 75 mm
    [PowerBox_PCB.kicad_pcb]
2026-05-28 added all models
    [DFN-10-3x3-0_5.STEP]
2026-05-28 Fixes
    Fixed model paths,
    Closed to prevent still open another device warning
    [DFN-10-3x3-0_5.STEP, HRO TYPE-C-31-M-12.step, Inductor - Part 1.step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]
2026-05-28 fix more relative paths
    [PowerBox_PCB-B_Cu.gbr, PowerBox_PCB-B_Mask.gbr, PowerBox_PCB-B_Paste.gbr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]
2026-06-01 added schematics as pdf
2026-06-02 fix bom
    bom
    [BMS.kicad_sch, Batt Charger.kicad_sch, Ideal_Diode.kicad_sch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]
2026-06-11 Changed HUSB238 to CH221K
    HUSB238 Went out of stock so changed to CH221K
    [Batt Charger.kicad_sch, Inductor - Part 1(1).step, PowerBox_PCB.kicad_pcb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]
2026-06-14 i finished and getting it made
    [Batt Charger.kicad_sch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]

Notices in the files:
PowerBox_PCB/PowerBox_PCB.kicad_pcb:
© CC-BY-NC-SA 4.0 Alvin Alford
